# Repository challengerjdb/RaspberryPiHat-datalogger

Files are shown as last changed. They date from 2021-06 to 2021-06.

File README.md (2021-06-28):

# RaspberryPiHat-datalogger

My name is Jacob Bendell, and I’m a student at the University of Pennsylvania studying Electrical Engineering.  I took this past year off from school to avoid online classes and intern at Amped Innovation, a start-up in the Bay Area that designs and builds solar home systems for people in developing countries.  There I worked on a Raspberry Pi project that collects and live-plots voltage, temperature, and battery capacity data.  Additionally, I created a Raspberry Pi hat circuit that enables these data collection features.  

The folder titled 'pythonscript' contains the files to run the data aquisition and live plotter features.  
The folder titled 'kicadhat' contains all the files and libraries for the data logger hat.

Feel free to reach out to me with any questions!
jbendell@seas.upenn.edu

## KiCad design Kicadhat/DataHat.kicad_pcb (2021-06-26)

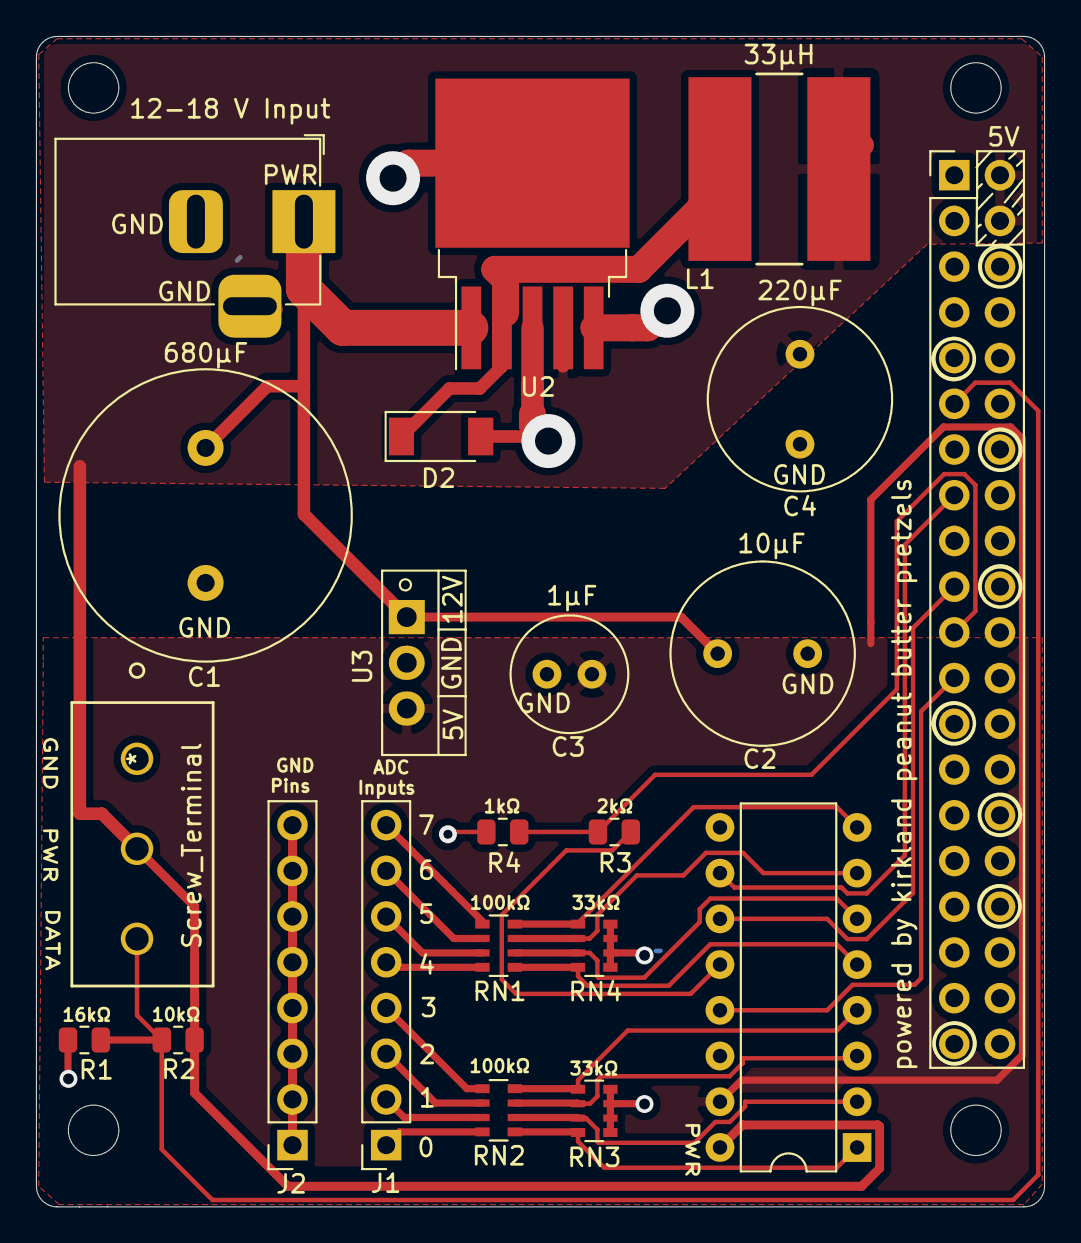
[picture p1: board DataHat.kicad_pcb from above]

Board: 2 copper layers, 56.0 x 65.0 mm, 22 parts (0 on the bottom side), 27 nets.

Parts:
C1: 680μF; C_Radial_D16.0mm_H25.0mm_P7.50mm
C2: 10μF; C_Radial_D10.0mm_H20.0mm_P5.00mm
C3: 1μF; C_Radial_D6.3mm_H11.0mm_P2.50mm
C4: 220μF; C_Radial_D10.0mm_H20.0mm_P5.00mm
D2: D_Schottky; D_SOD-128
J1, J2: Conn_01x08_Female; PinSocket_1x08_P2.54mm_Vertical
J3: Screw_Terminal; TB002-500-03BE
J5: Raspberry_Pi_2_3; PinHeader_2x20_P2.54mm_Vertical
J6: Barrel_Jack_Switch; BarrelJack_Horizontal
L1: 33μH; SRN1060-330M
R1: 16kΩ; R_0805_2012Metric
R2: 10kΩ; R_0805_2012Metric
R3: 2kΩ; R_0805_2012Metric
R4: 1kΩ; R_0805_2012Metric
RN1, RN2: 100kΩ; R_Array_Convex_4x0603
RN3, RN4: 33kΩ; R_Array_Convex_4x0603
U1: MCP3008; DIP-16_W7.62mm
U2: LM2596S-5; TO-263-5_TabPin3
U3: LM7805_TO220; TO-220-3_Vertical

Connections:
GND: C1.2, C2.2, C3.2, C4.2, D2.2, J2.1, J2.2, J2.3, J2.4, J2.5, J2.6, J2.7, J2.8, J3.1, J5.6, J5.9, J5.14, J5.20, J5.25, J5.30, J5.34, J5.39, J6.2, J6.3, R1.2, R4.2, RN3.5, RN3.6, RN3.7, RN3.8, RN4.5, RN4.6, RN4.7, RN4.8, U1.9, U1.14, U2.3, U2.5, U3.2
unnamed: C1.1, C2.1, J6.1, U2.1, U3.1
unnamed: C3.1, U1.15, U3.3
unnamed: C4.1, J3.2, J5.2, J5.4, L1.2, R2.1, U1.16, U2.4
unnamed: D2.1, L1.1, U2.2
unnamed: J1.1, RN2.4
unnamed: J1.2, RN2.3
unnamed: J1.3, RN2.2
unnamed: J1.4, RN2.1
unnamed: J1.5, RN1.4
unnamed: J1.6, RN1.3
unnamed: J1.7, RN1.2
unnamed: J1.8, RN1.1
unnamed: J3.3, J5.11, R1.1, R2.2
unnamed: J5.15, U1.10
unnamed: J5.19, U1.11
unnamed: J5.21, R3.2, R4.1
unnamed: J5.23, U1.13
unnamed: R3.1, U1.12
unnamed: RN1.5, RN4.4, U1.5
unnamed: RN1.6, RN4.3, U1.6
unnamed: RN1.7, RN4.2, U1.7
unnamed: RN1.8, RN4.1, U1.8
unnamed: RN2.5, RN3.4, U1.1
unnamed: RN2.6, RN3.3, U1.2
unnamed: RN2.7, RN3.2, U1.3
unnamed: RN2.8, RN3.1, U1.4

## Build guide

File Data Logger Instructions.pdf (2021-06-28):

## RASPBERRY Pi DATA LOGGER INSTRUCTIONS

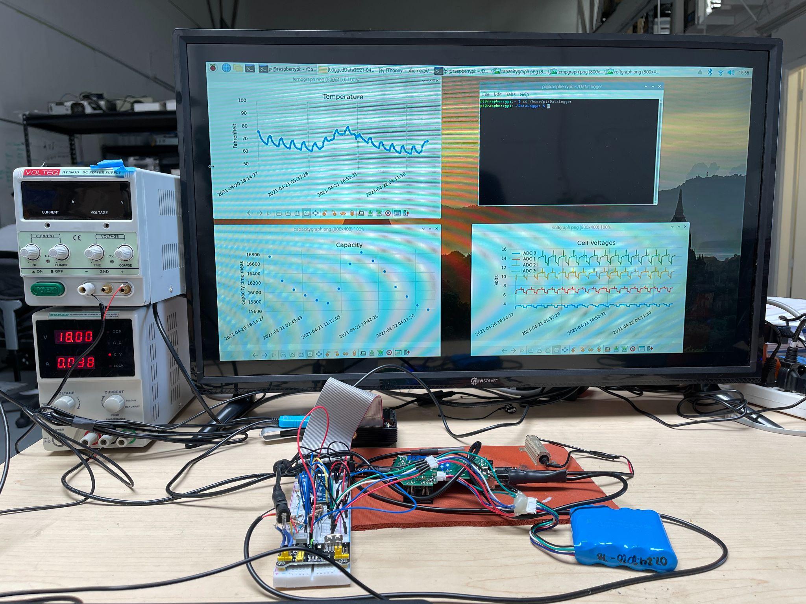
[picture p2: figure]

Setting up a new Raspberry Pi
- Downloading libraries
1. at the command prompt, enter sudo pip3 install keyboard
2. at the command prompt, enter sudo apt install python3-pandas
3. at the command prompt, enter sudo pip3 install adafruit-blinka
4. at the command prompt, enter sudo pip3 install adafruit-circuitpython-mcp3xxx
- SPI Enable
- at the command prompt, enter sudo raspi-config
- select “Interfacing Options”
- select and enable “SPI”
- if prompted to reboot select “Yes”
- 1-wire thermocouple setup:
1. at the command prompt, enter sudo nano /boot/config.txt
2. then add or modify existing to be dtoverlay=w1-gpio,gpiopin=17 to the bottom of the file
3. Exit Nano, and reboot the Pi with sudo reboot
- disable screen blanking
1. In RPi Configuratio nWindow, click on Display Tab
2. Look for the Screen Blanking row, click Disable. Then click OK.
3. A window will open and asks if you would like to reboot the RPi. Click Yes.
- don’t forget to calibrate the ADC, instructions are below

Running the program:
First, before starting to data log is to configure ‘main.py’. Here the user configures different variables controlling sample rates, which ADC channels to read, file paths, and much MUCH more!

Next, the user must run the desired data logging program:
at the command prompt, cd to the directory where the ‘main.py’, ‘plotter.py’ and ‘start-logging.sh’ are located

Option 1: Running DataQ with Live Plotting
at the command prompt, enter:
sh start-logging.sh
- this is a bash shell script that does all the same functions as DataQ from Option 1, but ALSO runs a live plotting program to display the data in real time on the display

Option 2: Running DataQ standalone
at the command prompt, enter:
sudo python3 -c ‘import main; main.run_main()’
- this will acquire data, live save the data to a CSV, and upon termination save a copy of the data CSV in a folder with graphs of temp, capacity, and voltage

LAST, after the data has been acquired the user ends the program
- at the command terminal running the program, hold ‘alt+s’
- this action completes the data logging and saves the CSV file and data graphs
- after acquiring large amounts of data it may take a few minutes to plot and save the graphs, be patient

Structure and notes:
Data Input:
- Temperature Sensor: collected using DS18B20 sensor, 1-wire interface, probe is on 1 meter cable

- Serial Communication: collected using smart cable connected between RPi USB port and SHS USB port. Note that this data is cleaned and processed specifically for the capacity printouts in life cycler mode. This capacity number is calculated on the SHS and not by the RPi.
- Voltage Data: collected using MCP3008, the RPi Hat has 8 female sockets where jumper wires are connected for voltage input.
File Structure:
- ‘currentloggeddata.csv’ is created and gets written to in real time as the program runs
- A folder created at the beginning of the program. Once the termination sequence has been initiated by pressing ‘alt+s’, a copy of ‘currentloggeddata’ and the data plots are saved in this folder

Important Notes:
- ‘currentloggeddata’ is overwritten each time the program is run
- The location of the saved files is specified by the user in ‘main.py’
- Notice the name of the folder has the exact time the program began running and the individual files saved inside have the time the program was completed
- if the data acquisition were to be abruptly interrupted(like by a blown circuit breaker LOL) the data up to that point will be saved in ‘currentloggeddata.csv’. Before starting data logging again, this data could be manually copied by the user to a new CSV to be saved

Circuit Notes:
- The MAX input to the ADC is 20V for this set up. Damage will be caused by inputting larger voltages to the ADC.
- 3:1 voltage dividers are used to reduce the input voltage to within the 0-5V range. 5V is the operating voltage on the MCP3008 and thus 5V is used as the reference voltage.
- To increase the input voltage the ADC resistor pack values must be changed. Don’t forget to change the voltage divider coefficient inside main.py after making this change!
- 3.3V is the max input to the RPi’s GPIO Pins. Voltage dividers are necessary. You will notice a 2:1 voltage divider being used between the MISO pin on the RPi and the ADC. This is used because the ADC is running on 5V.

- The 5V power produced by the Raspberry Pi is noisy and unreliable. Powering the circuit by an external power source is highly recommended
- Serial connection most easily made using USB UART cable
- Individual Cell Voltages:
- if you want to find individual cell voltages turn v_sub True in ‘main.py’
- this feature subtracts the differences between each ADC channel to report individual cell voltage
- For example, with v_sub = True a pack with a total voltage of 13.8V, 3.45V per each cell would be graphed and recorded in the CSV. If v_sub = False in this scenario, 3.45, 6.9, 10.35, and 13.8 would be graphed and recorded in the CSV.
- When v_sub = True make sure the lowest voltage input is connected to the lowest ADC channel you are using. The second lowest voltage input is connected to the second lowest ADC channel you are using, and so on...
- The adapter pictured below is what is used to sample the cell voltages

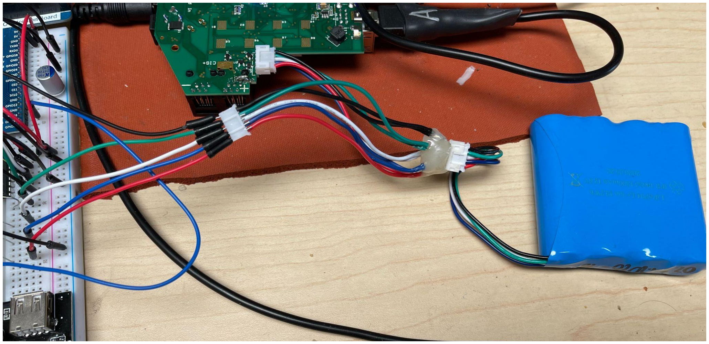
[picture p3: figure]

- Pictured below is the layout of the breadboard circuit

Code:

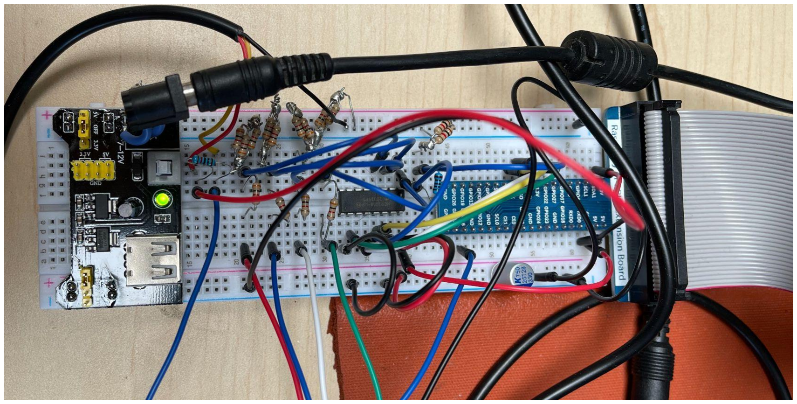
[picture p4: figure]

- The code to run the data logger can be found here: https://gitlab.com/ampedinnovation/datalogger.git
- dataQ.py → temperature, voltage, and serial data collected and saved into a CSV file
- plotter.py → live plotting and plots at end of data logging run created and saved here
- main.py → functions as a config file for the user to specify their settings
- start-logging.sh → sh file necessary for running the plotter and dataQ files simultaneously

Calibrating ADC Input:
- Due to variation between the RPi Hat circuits, calibrating the ADC is necessary
- The middle term(v_ref) of the ADC tuples in ‘main.py’ is used for calibration. In DataQ.py, v_ref is multiplied by the raw ADC value.

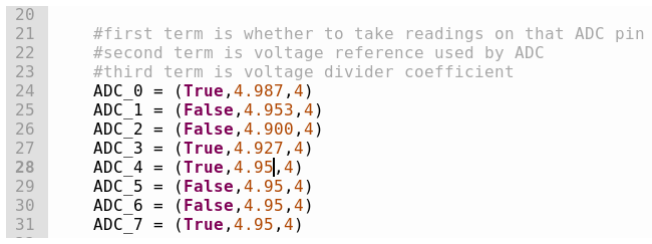
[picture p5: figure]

Below is the process I used to find an accurate value for v_ref:
- Using a trusted power supply, apply a voltage near the expected level you will be measuring on that specific ADC input channel.
- Turn on printing by uncommenting the lines of code in dataQ.py seen below

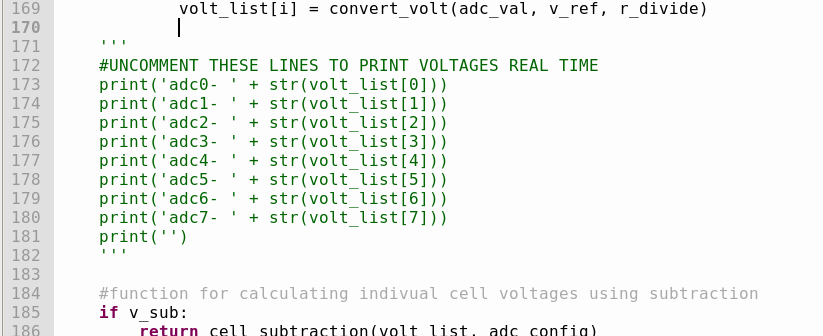
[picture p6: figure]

- at the command prompt, enter:
sudo python3 -c ‘import main; main.run_main()’
- by running this and not the bash script, live plotting does not take place. This is useful because when calibrating the ADC you must run the program many times to hone in on the right v_ref value. Closing all the live plotter windows gets annoying when doing this. Hopefully Michael and Will add auto closing of the plots, so this step is no longer necessary
- adjust v_ref in main.py until the value that is printed matches the power supply

USB Drive:
- path_to_save in ‘main.py’ is where the user specifies the the location that all files will be saved
- Saving to a USB drive is useful but finding the correct path can be tricky
- Here are the steps to manually find the path: (An example image of this can be seen below)
1. at the command prompt, enter cd /media/pi
2. at the command prompt, enter ls
this lists all the USB devices
3. at the command prompt, enter cd __fill in USB device name__ now keep on entering device names until Permission is not denied
4. at the command prompt, enter ls
if the files listed match the ones in your desired location you know you’ve found the name of the correct USB device
- The last step is to change path_to_save in ‘main.py’ to ‘/media/pi/__fill in USB device name__’

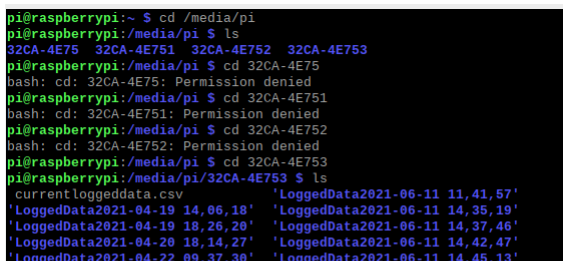
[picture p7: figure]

- if still experiencing problems saving to the USB drive try manually mounting the USB drive to the Raspberry Pi. The link below walks you through this. http://raspi.tv/2012/mount-a-usb-flash-drive-on-raspberry-pi

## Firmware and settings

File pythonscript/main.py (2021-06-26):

import dataQ

#The User may configure Temperature, Voltage, Serial, and Files to their liking

def main_init():
    '''TEMPERATURE'''
    #set to TRUE if want to temperature measurements, FALSE if not
    read_temp = True
    #set to integer that is desired number of seconds between each sample being taken
    sample_rate_temp = 5

    '''VOLTAGE'''
    #set to TRUE if want to voltage measurements, FALSE if not
    read_volt = True
    #set to integer that is desired number of seconds between each sample being taken
    sample_rate_volt = 5
    
    #subtracts differences in voltages
    #when this is true the lowest voltage input should be at the lowest ADC channel you are using
    #the second lowest voltage input should be at the next lowest ADC channel, and so on... 
    v_sub = False
    
    #first term is whether to take readings on that ADC pin
    #second term is voltage reference used by ADC
    #third term is voltage divider coefficient
    
    ADC_0 = (True,5.139,4)
    ADC_1 = (True,5.099,4)
    ADC_2 = (True,5.085,4)
    ADC_3 = (True,5.106,4)
    ADC_4 = (False,5.118,4)
    ADC_5 = (False,5.147,4)
    ADC_6 = (False,5.111,4)
    ADC_7 = (False,5.098,4)
    
    '''SERIAL'''
    #set to TRUE if want to serial measurements, FALSE if not
    read_serial_capacities = True
    #set to integer that is desired number of seconds between each sample being taken
    sample_rate_serial = 15
    #path to serial in of RPi
    path_serial = '/dev/ttyUSB0'
    baud_rate = 9600

    '''FILES'''
    #location to save all files and graphs
    path_to_save =  '/media/pi/32CA-4E753'
    #path_to_save =  '/home/pi/logdata'
    
#do not edit below this
#####################################
    #list of ADC configuration tuples
    adc_config = [ADC_0,ADC_1,ADC_2,ADC_3,ADC_4,ADC_5,ADC_6,ADC_7]
    #dictionary of sampling booleans and rates
    sampling_dict = {'temp':(read_temp, sample_rate_temp),'volt':(read_volt, sample_rate_volt),'serial':(read_serial_capacities, sample_rate_serial)}
    
    return sampling_dict, path_serial, baud_rate, v_sub, adc_config, path_to_save

def run_main():
    #initializing all values
    sampling_dict, path_serial, baud_rate, v_sub, adc_config, path_to_save = main_init()
    
    #tuple to be passed into dataQ
    config_tuple = (sampling_dict, path_serial, baud_rate, v_sub, adc_config, path_to_save)

    #initiating dataQ
    dataQ.record_data(config_tuple)

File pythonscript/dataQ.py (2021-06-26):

#for multiple
import os
import time
import datetime
import shutil
import keyboard
import plotter
import os.path
import sys

#for temp sensor
import glob
 
#for voltmeter
import busio
import digitalio
import board
import adafruit_mcp3xxx.mcp3008 as MCP
from adafruit_mcp3xxx.analog_in import AnalogIn

#for serial data
import serial


#################################################################

#temperature probe

def temp_init():
    device_file = ''
    os.system('modprobe w1-gpio')
    os.system('modprobe w1-therm')
    
    base_dir = '/sys/bus/w1/devices/'
    folder_object = glob.glob(base_dir + '28*')
    if(len(folder_object)):
        device_folder = folder_object[0]
    else:
        print('\nERROR: Failed to initialize temperature sensor, try reconnecting the sensor or set read_temp = False\n')
        sys.exit(1)
    device_file = device_folder + '/w1_slave'
    return device_file

#reads thermocouple raw data
def read_temp_raw(temp_device_file):
    f = open(temp_device_file, 'r')
    lines = f.readlines()
    
    f.close()
    
    return lines
 
#calls read_temp_raw, converts data into C and F
def read_temp(temp_device_file):
    lines = read_temp_raw(temp_device_file)
    
    
    #setting default values for error if no temp able to be measured
    temp_c = 'empty'
    temp_f = 'empty'
    
    #sometime read_temp_raw is empty list, this deals with that
    while len(lines) < 1:
        time.sleep(0.2)
        lines = read_temp_raw(temp_device_file)
        
    #finding temps in raw data then converting to C and F and returning
    equals_pos = lines[1].find('t=')
    if equals_pos != -1:
        temp_string = lines[1][equals_pos+2:]
        temp_c = float(temp_string) / 1000.0
        
        #calculating negative temperatures
        #operating temp of temp sensor -50 to 125 C
        if temp_c > 200:
            temp_c = temp_c - 4096
            
        temp_f = temp_c * 9.0 / 5.0 + 32.0
        
        #print(temp_c)
    
    return temp_c, temp_f
            
#################################################################

#voltmeter
    
def volt_init():
    # create the spi bus
    spi = busio.SPI(clock=board.SCK, MISO=board.MISO, MOSI=board.MOSI)

    # create the cs (chip select)
    cs = digitalio.DigitalInOut(board.D22)

    # create the mcp object
    mcp = MCP.MCP3008(spi, cs)

    # create an analog input channel on pin 0 and 1
    chan0 = AnalogIn(mcp, MCP.P0)
    chan1 = AnalogIn(mcp, MCP.P1)
    chan2 = AnalogIn(mcp, MCP.P2)
    chan3 = AnalogIn(mcp, MCP.P3)
    chan4 = AnalogIn(mcp, MCP.P4)
    chan5 = AnalogIn(mcp, MCP.P5)
    chan6 = AnalogIn(mcp, MCP.P6)
    chan7 = AnalogIn(mcp, MCP.P7)
    
    return [chan0, chan1, chan2, chan3, chan4, chan5, chan6, chan7]

#converts adc value to relevant voltage
def convert_volt(adcvalue, v_ref, r_divide):
    
    ratio = adcvalue / 65535
    
    return ratio * r_divide * v_ref

#takes in raw adc values and returns the most common one
def adc_acquire(channel_list, chan):
    #taking in raw adc values
    adc_list =[]
    window = []
    
    sample_size = 20
    cut_off_window = 5
    
    for i in range(0,sample_size):
        adc_list.append(channel_list[chan].value)
    
    #windowing
    adc_asc = sorted(adc_list)
    
    for i in range(cut_off_window,sample_size-cut_off_window):
        window.append(adc_asc[i])
    
    window_av = sum(window) / len(window)
    
    return window_av
    

#calculates individual cell voltages
def cell_subtraction(volt_list, adc_config):
    sub_list = ['','','','','','','','']
    last_v = 0
    
    #calculating individual cell voltages
    for i in range(0,len(sub_list)):
        #tuple unpack
        (read_bool, v_ref, r_divide) = adc_config[i]
        if read_bool:
            sub_list[i] = volt_list[i] - last_v
            last_v = volt_list[i]
    
    #returns float values
    return sub_list
    
def read_volt(channel_list, v_sub, adc_config):
    #initializing list of voltages to return
    #returns empty string if no values taken
    volt_list = ['','','','','','','','']
    
    for i in range(0,len(volt_list)):
        #tuple unpack
        (read_bool, v_ref, r_divide) = adc_config[i]
        #takes voltage reading and edits return list
        if read_bool:
            #gets raw adc value
            adc_val = adc_acquire(channel_list, i)
            #converts adc value to voltage
            volt_list[i] = convert_volt(adc_val, v_ref, r_divide)
            
    '''
    #UNCOMMENT THESE LINES TO PRINT VOLTAGES REAL TIME
    print('adc0- ' + str(volt_list[0]))
    print('adc1- ' + str(volt_list[1]))
    print('adc2- ' + str(volt_list[2]))
    print('adc3- ' + str(volt_list[3]))
    print('adc4- ' + str(volt_list[4]))
    print('adc5- ' + str(volt_list[5]))
    print('adc6- ' + str(volt_list[6]))
    print('adc7- ' + str(volt_list[7]))
    print('')
    '''

    #function for calculating indivual cell voltages using subtraction
    if v_sub:
        return cell_subtraction(volt_list, adc_config)
    else:
        #returns voltage measurement floats
        return volt_list

#################################################################

#serial

def serial_init(path_serial, baud_rate):
    serial.Serial(path_serial, baud_rate)
    


def read_serial(path_serial):
    #reading serial raw output
    with open(path_serial, encoding="utf8", errors='ignore') as f:
        #must call readline twice bc of print statement
        junk = f.readline()
        contents = f.readline()
    
    #is it a number or junk?
    capacity_num = ''
    for char in contents:
        if char in ['1','2','3','4','5','6','7','8','9','0',',','#']:
            capacity_num = capacity_num + str(char)
         
    #returns empty string if no capacity at the moment     
    return capacity_num
    
#end of serial
    
###############################################
#file set up
def file_init(path_write):
    #folder for graph images and old data logs
    folder = 'LoggedData{}'.format(datetime.datetime.now().strftime("%Y-%m-%d %H,%M,%S"))
    folder_path = os.path.join(path_write,folder)
    try:
        os.mkdir(folder_path)
    except:
        print('failed to make directory -->' + folder_path)
        sys.exit(1)
        
    #making current data log csv file
    file_name = 'currentloggeddata.csv'
    curr_log_name = os.path.join(path_write, file_name)
    #creating column headers in CSV file
    file = open(curr_log_name, 'w')
    string_to_write = 'Time,Temp C,Temp F,ADC 0,ADC 1,ADC 2,ADC 3,ADC 4,ADC 5,ADC 6,ADC 7,Cycle Num,Capacity\n'
    file.write(string_to_write)
    file.close()
    
    return curr_log_name, folder_path
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

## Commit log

2021-06-26 Create Kicad Misc
2021-06-28 Create kicadmisc

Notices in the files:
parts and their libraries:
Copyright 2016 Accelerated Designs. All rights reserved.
